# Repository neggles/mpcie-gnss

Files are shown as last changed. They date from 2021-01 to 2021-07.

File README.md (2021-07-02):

# mPCIe-GNSS (mPCIe-LC6L)  

This is a little miniPCIe card I designed to hold a [Quectel LC86L](https://www.quectel.com/product/gnss-lc86l/) GNSS module, with a timepulse header and a backup supercap.

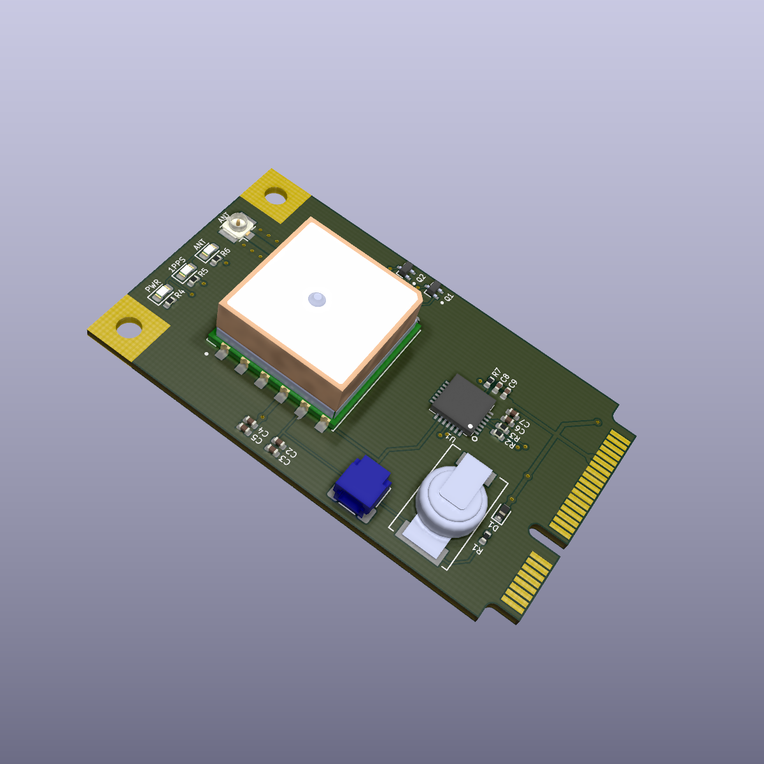
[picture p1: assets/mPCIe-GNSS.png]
KiCad raytraced board render


## Repository Structure
- `mPCIe-GNSS` contains the main schematics and board drawing
- `mPCIe-GNSS/mPCIe-GNSS.pretty` contains the board-specific footprints
- `mPCIe-GNSS/mPCIe-GNSS-archive.lib` contains the board-specific symbols

I had this made by [JLCPCB](https://jlcpcb.com) using their 1mm thick PCBs, and elected to get them to assemble most of it - while all of the parts except the supercapacitor, connectors, and GNSS module are in their extended part library, it didn't make sense to spend $6 on extended part fees for two assembled boards, so I skipped the transistors and diode.

## Building
Simply call `make` in the top-top level directory. The `build` directory will
them contain:

- the main mPCIe board
- A panelized version of said board
- zipped gerbers for the boards you can directly use for manufacturing
- zipped gerbers and SMT assembly BOM/position files for JLCPCB's SMT assembly service for the single-board version.

Makefile uses [Jan Mrázek](https://github.com/yaqwsx)'s [KiKit](https://github.com/yaqwsx/KiKit), which I cannot recommend enough, and therefore has to be available on your system.

Jan's [jlcparts](https://yaqwsx.github.io/jlcparts/) app was also extremely useful in narrowing down part choices based on what JLCPCB have available.

-----
### **IMPORTANT NOTE:** If you give JLCPCB these files as-is, *please* verify the orientation of every part before submitting.

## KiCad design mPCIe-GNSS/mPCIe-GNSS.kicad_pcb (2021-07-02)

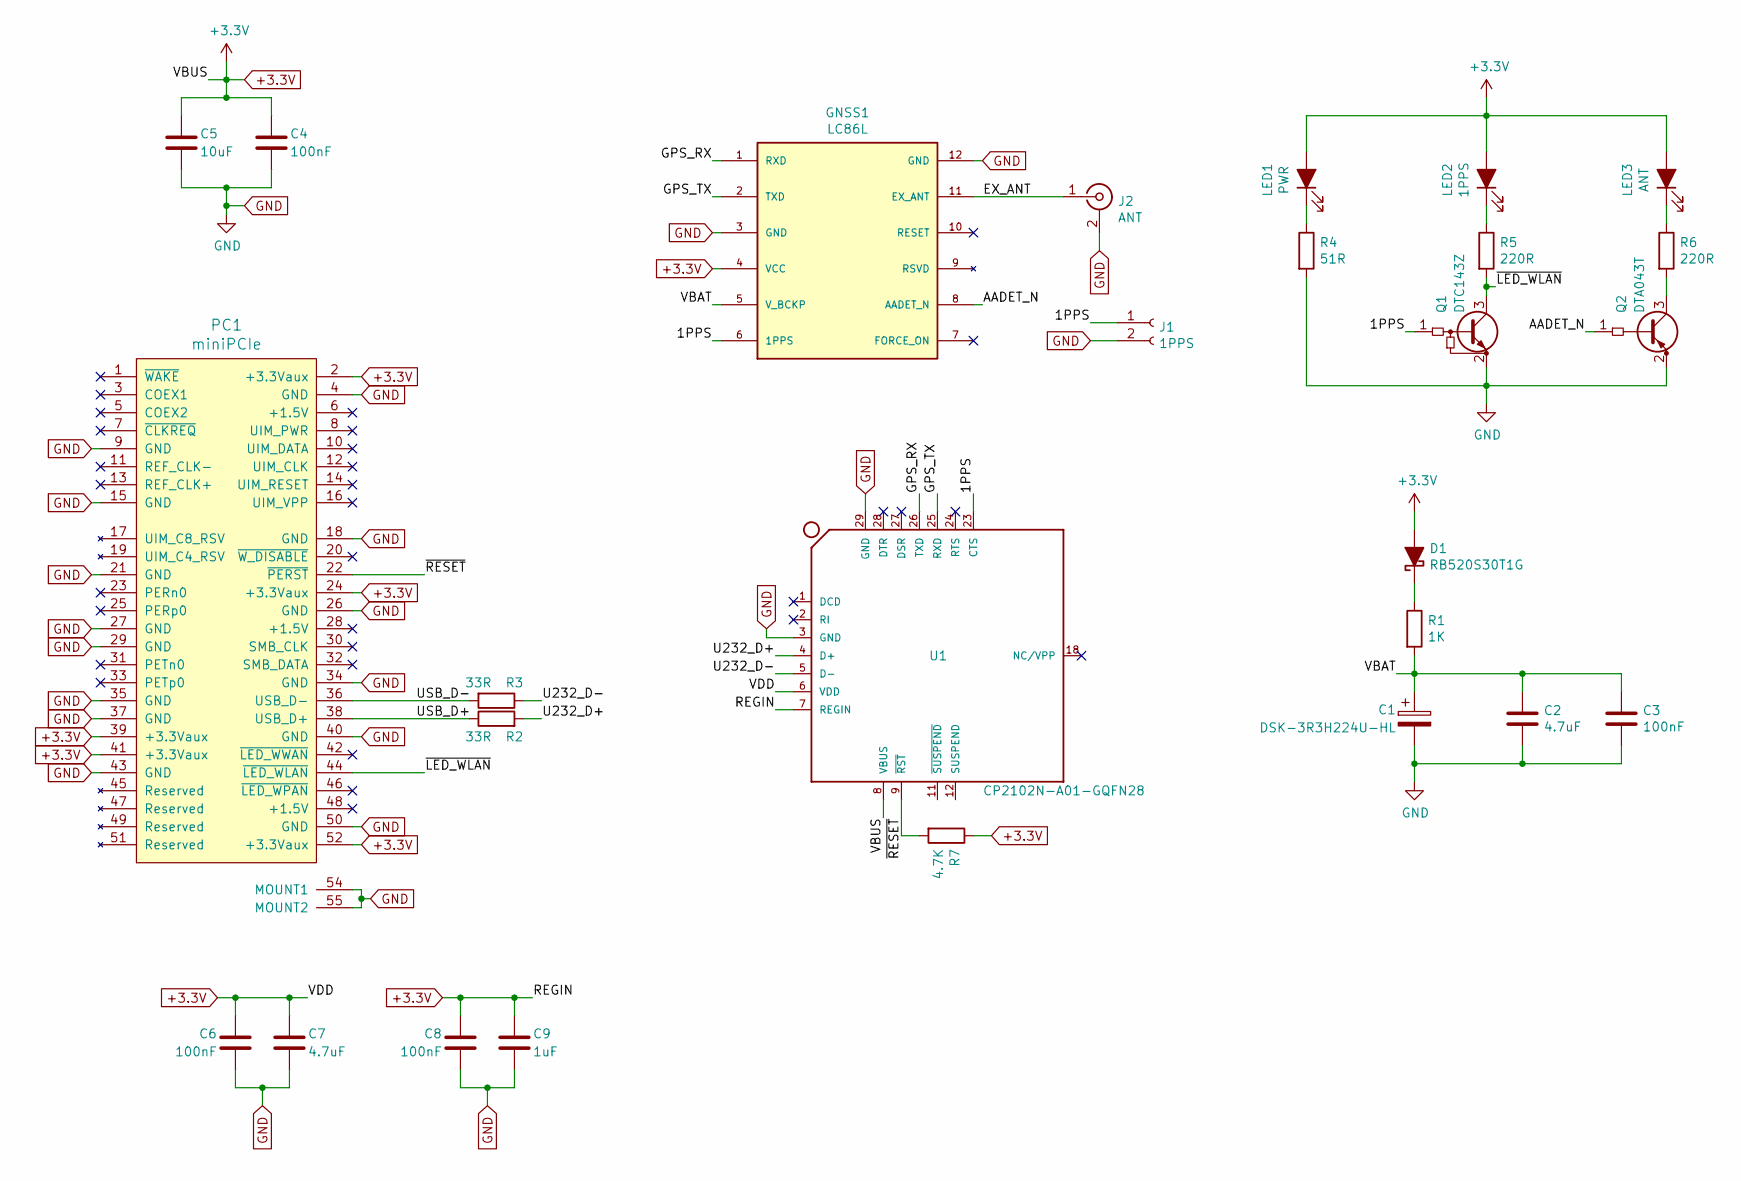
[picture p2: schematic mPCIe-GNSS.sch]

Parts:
C1: DSK-3R3H224U-HL; CAP_DSK-3R3H224U-HL
C2, C7: 4.7uF; C_0402_1005Metric; LCSC C23733
C3, C4, C6, C8: 100nF; C_0402_1005Metric; LCSC C1525
C5: 10uF; C_0402_1005Metric; LCSC C15525
C9: 1uF; C_0402_1005Metric; LCSC C52923
D1: RB520S30T1G; D_SOD-523; LCSC C154821
GNSS1: LC86L; XCVR_LC86L
J1: 1PPS; JST_SH_SM02B-SRSS-TB_1x02-1MP_P1.00mm_Horizontal_3D
J2: ANT; U.FL_Hirose_U.FL-R-SMT-1_Vertical
LED1: PWR; LED_0603_1608Metric_SnapModel; LCSC C72041
LED2: 1PPS; LED_0603_1608Metric_SnapModel; LCSC C72038
LED3: ANT; LED_0603_1608Metric_SnapModel; LCSC C72043
PC1: miniPCIe; mini-PCIe_F1_Full_v517
Q1: DTC143Z; Q_EMT3F
Q2: DTA043T; Q_EMT3F
R1: 1K; R_0402_1005Metric; LCSC C11702
R2, R3: 33R; R_0402_1005Metric; LCSC C25105
R4: 51R; R_0402_1005Metric; LCSC C25125
R5, R6: 220R; R_0402_1005Metric; LCSC C25091
R7: 4.7K; R_0402_1005Metric; LCSC C25900
U1: CP2102N-A01-GQFN28; QFN28G_0.5-5X5MM; MPN CP2102-GMR; LCSC C6568

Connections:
+3.3V: C4.1, C5.2, C6.2, C7.1, C8.2, C9.1, D1.2 (A), GNSS1.4 (VCC), LED1.2 (A), LED2.2 (A), LED3.2 (A), PC1.2 (+3.3Vaux), PC1.24 (+3.3Vaux), PC1.39 (+3.3Vaux), PC1.41 (+3.3Vaux), PC1.52 (+3.3Vaux), R7.1, U1.6 (VDD), U1.7 (REGIN), U1.8 (VBUS)
/1PPS: GNSS1.6 (1PPS), J1.1, Q1.1 (B), U1.23 (CTS)
/AADET_N: GNSS1.8 (AADET_N), Q2.1 (B)
/EX_ANT: GNSS1.11 (EX_ANT), J2.1 (In)
/GPS_RX: GNSS1.1 (RXD), U1.26 (TXD)
/GPS_TX: GNSS1.2 (TXD), U1.25 (RXD)
/U232_D+: R2.2, U1.4 (D+)
/U232_D-: R3.1, U1.5 (D-)
/USB_D+: PC1.38 (USB_D+), R2.1
/USB_D-: PC1.36 (USB_D-), R3.2
/VBAT: C1.1, C2.1, C3.1, GNSS1.5 (V_BCKP), R1.2
/~LED_WLAN: PC1.44 (~LED_WLAN), Q1.3 (C), R5.2
/~RESET: PC1.22 (~PERST), R7.2, U1.9 (~RST)
GND: C1.2, C2.2, C3.2, C4.2, C5.1, C6.1, C7.2, C8.1, C9.2, GNSS1.3 (GND), GNSS1.12 (GND), J1.2, J2.2 (Ext), PC1.4 (GND), PC1.9 (GND), PC1.15 (GND), PC1.18 (GND), PC1.21 (GND), PC1.26 (GND), PC1.27 (GND), PC1.29 (GND), PC1.34 (GND), PC1.35 (GND), PC1.37 (GND), PC1.40 (GND), PC1.43 (GND), PC1.50 (GND), PC1.54 (MOUNT1), PC1.55 (MOUNT2), Q1.2 (E), Q2.2 (E), R4.2, U1.3 (GND), U1.29 (GND)
unnamed: D1.1 (K), R1.1
unnamed: LED1.1 (K), R4.1
unnamed: LED2.1 (K), R5.1
unnamed: LED3.1 (K), R6.1
unnamed: Q2.3 (C), R6.2

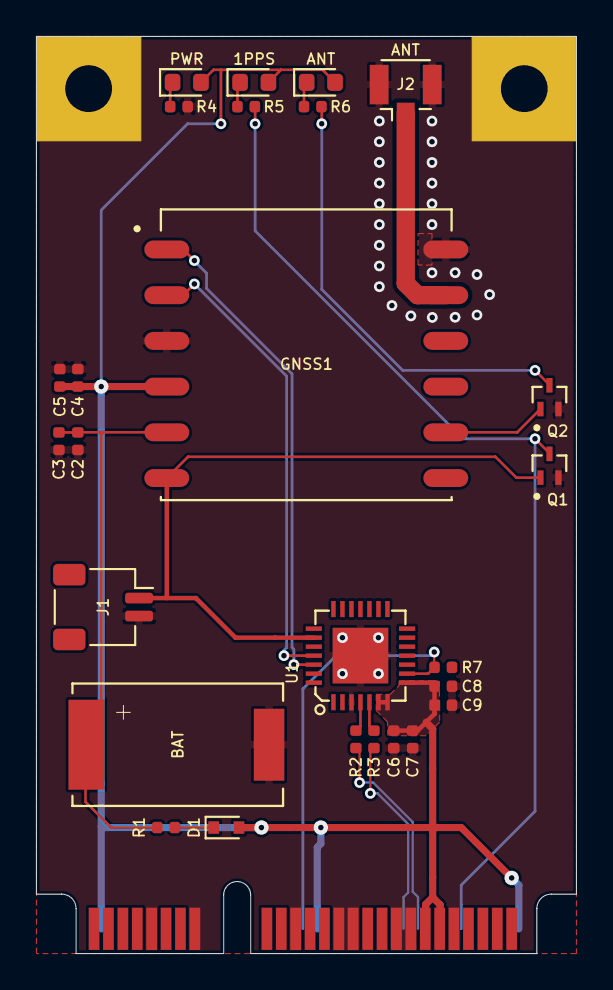
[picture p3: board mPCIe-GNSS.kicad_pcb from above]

Board: 2 copper layers, 30.0 x 51.0 mm, 27 parts (0 on the bottom side), 19 nets.

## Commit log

2021-01-23 first ver
    [mPCIe-GNSS.kicad_pcb, mPCIe-GNSS.sch]
2021-01-23 version 0.2
    [mPCIe-GNSS-B_Mask.gbs, mPCIe-GNSS-B_SilkS.gbo, mPCIe-GNSS-Back.gbl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]
2021-01-23 version 0.3
    [bom.csv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]
